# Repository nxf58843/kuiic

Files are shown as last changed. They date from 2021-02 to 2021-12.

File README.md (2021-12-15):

# KUIIC

## K32L2B USB to IIC Kit

This board is a tiny USB to Qwiic development board in a bread-board friendly DIP form factor.  In addition to micro USB and Qwiic connectors, it also has a reset button, RGB LED, and footprint for SPI flash expansion on the back of the board.  The pinout and form factor are designed to be compatible with the Seeeduino XIAO board.  The MCU is an NXP K32L2B Arm Cortex-M0+ with crystal-less USB and integrated VBUS to 3V regulator.  

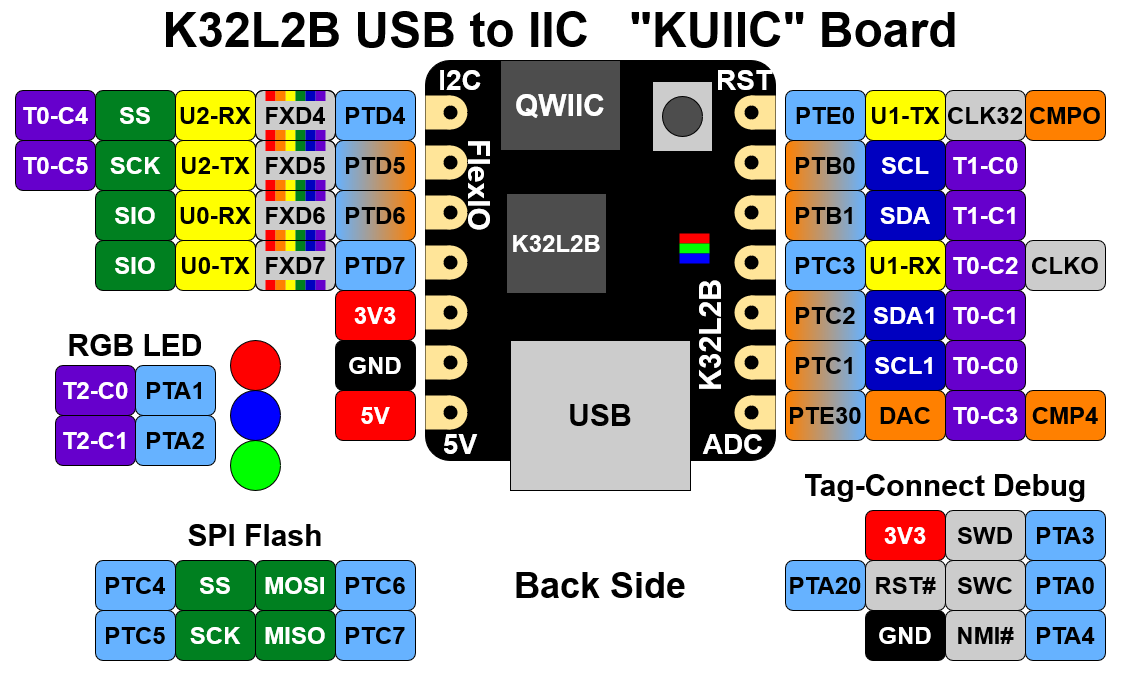
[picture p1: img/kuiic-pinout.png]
Kuiic Pinout


## Software Support

This board is currently supported by the open source [TinyUSB](https://docs.tinyusb.org/en/latest/) and Adafruit's [TinyUF2](https://github.com/adafruit/tinyuf2) to enable drag-n-drop firmware updates.

## Board Design Files
The KiCad source files are included in this repository along with a [pdf copy of the schematic](out/kuiic.pdf).

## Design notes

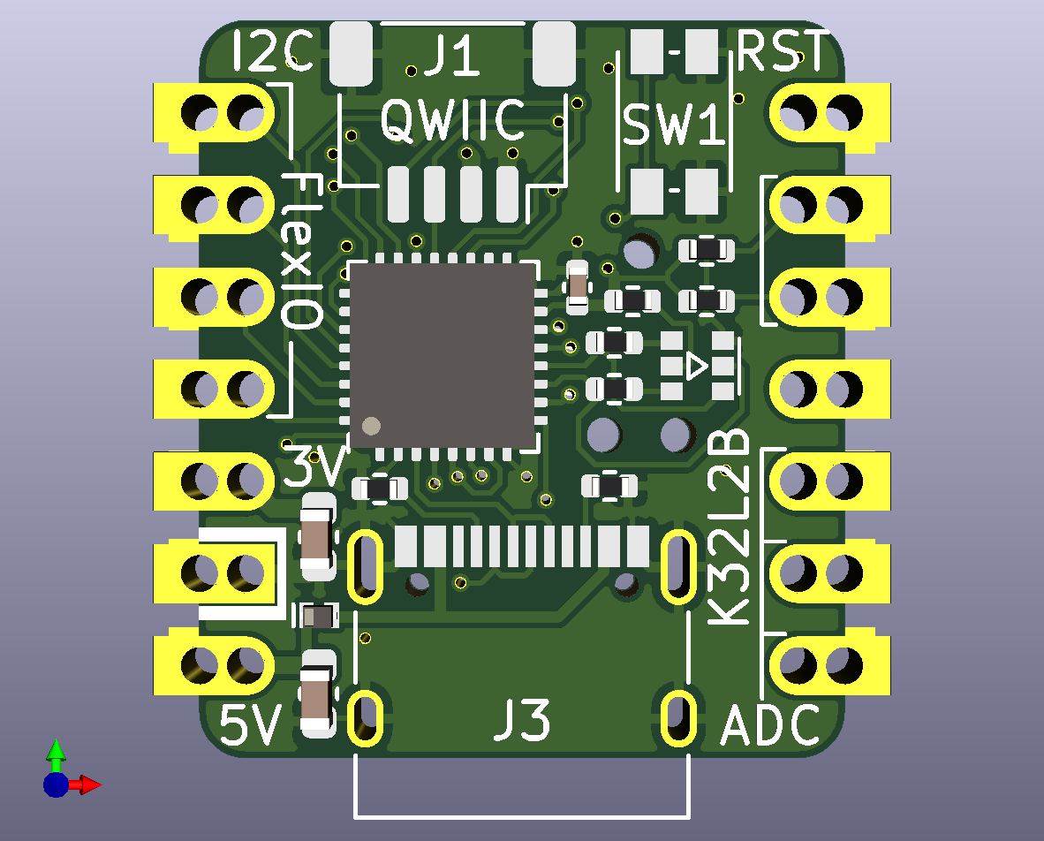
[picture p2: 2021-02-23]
img/k3d-top.png

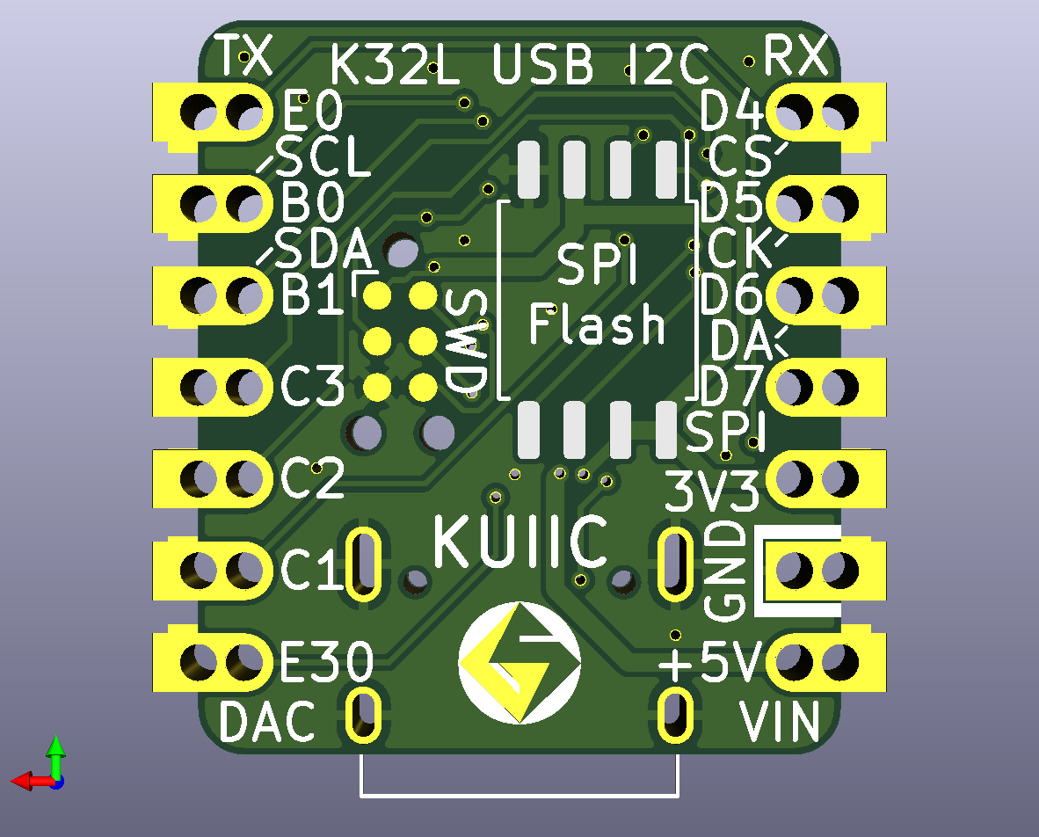
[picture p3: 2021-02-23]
img/k3d-bot.png

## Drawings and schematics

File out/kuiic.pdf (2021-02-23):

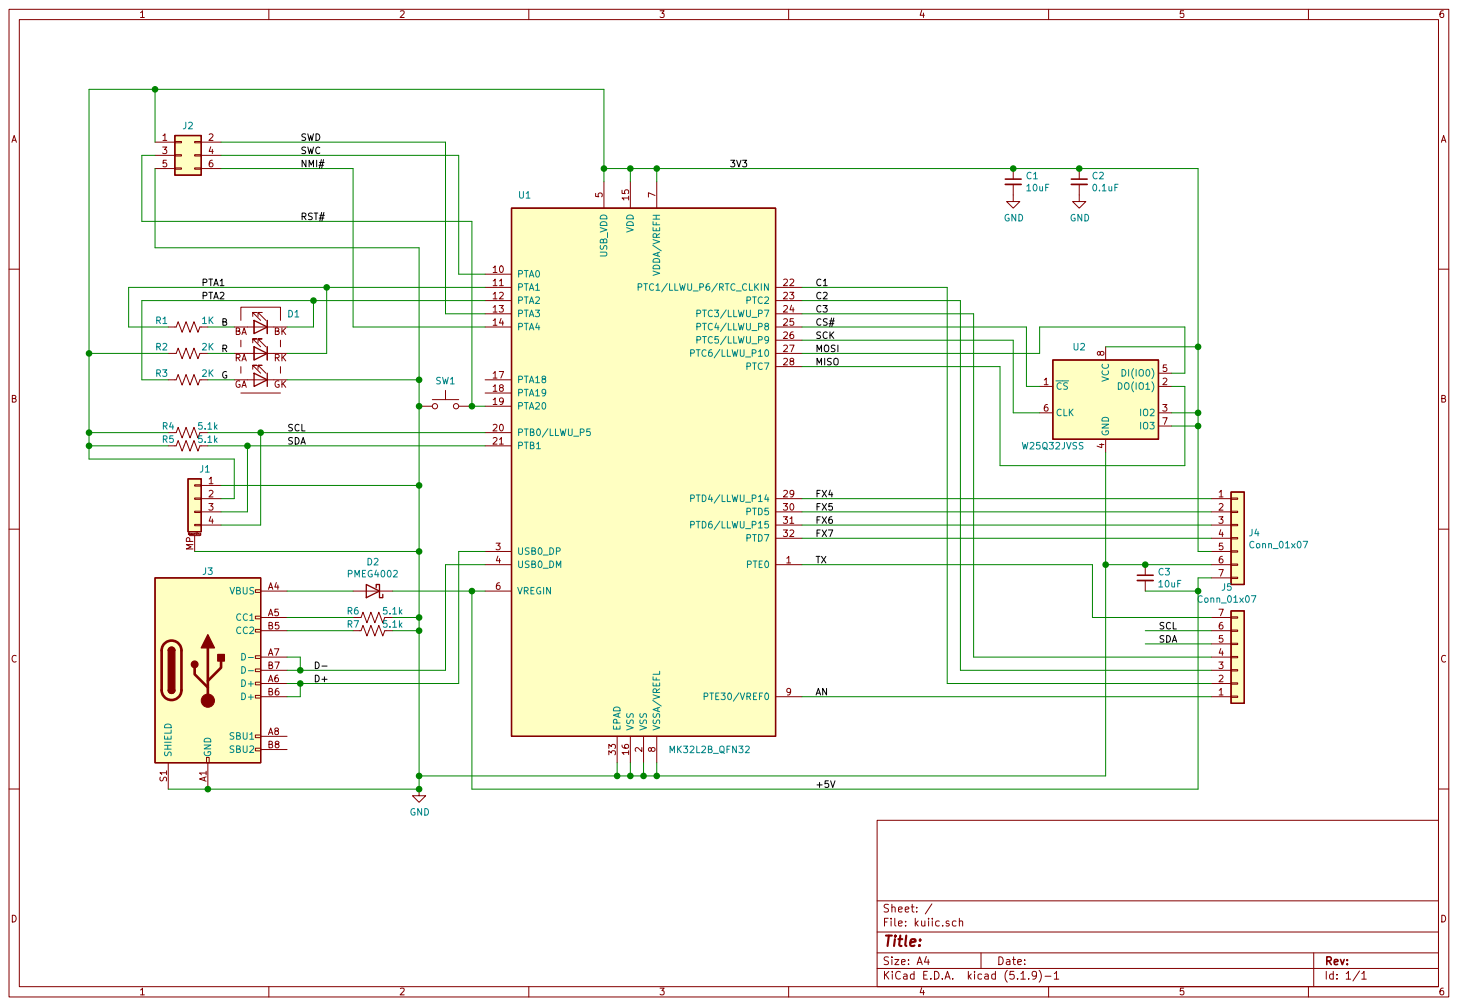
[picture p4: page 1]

TXC1 CS# FX7 SCK MOSI MISO

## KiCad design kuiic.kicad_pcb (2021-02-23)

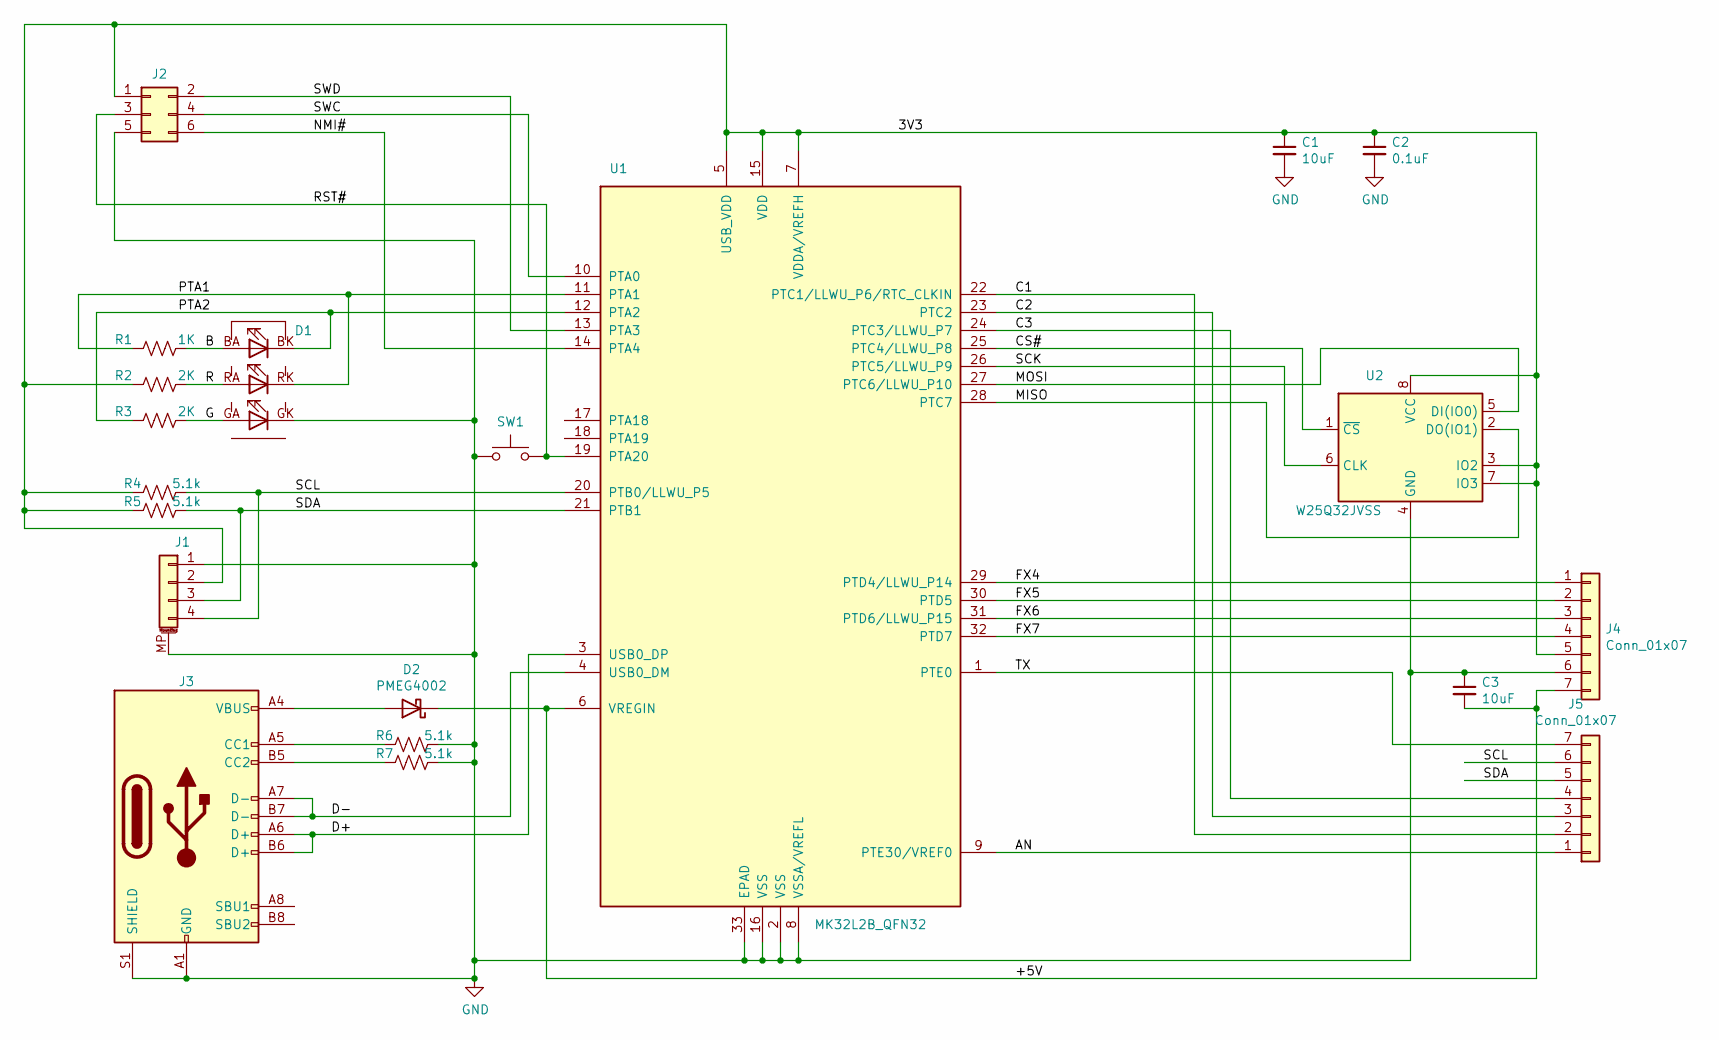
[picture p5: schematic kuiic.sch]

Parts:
C1, C3: 10uF; C_0603_1608Metric; MPN CL10A106KP8NNNC
C2: 0.1uF; C_0402_1005Metric; MPN CC0402KRX7R7BB104
D1: LED_RGB; LED_E6C1615; MPN E6C1615RGBC3UDA
D2: PMEG4002; D_SOD-882; MPN pmeg3005el
J1: Conn_01x04_MountingPin; QWIIC; MPN SM04B-SRSS-TB
J2: Conn_02x03_Odd_Even; Tag-Connect_TC2030-IDC-NL_2x03_P1.27mm_Vertical; MPN DNP
J3: USB_C_Receptacle_USB2.0; USB_C_Receptacle_XKB_U262-16XN-4BVC11; MPN U262-161N-4BVC11
J4, J5: Conn_01x07; PinHeader_1x07_P2.54mm_castle; MPN DNP
R1: 1K; R_0402_1005Metric; MPN RC0402JR-071KL
R2, R3: 2K; R_0402_1005Metric; MPN RC0402JR-072KL
R4, R5, R6, R7: 5.1k; R_0402_1005Metric; MPN RC0402JR-075K1L
SW1: SW_Push; SW_Push_4pin_3.0x3.65mm; MPN TS342A4P-WZ
U1: MK32L2B_QFN32; QFN-32-1EP_5x5mm_P0.5mm_EP3.45x3.45mm; MPN K32L2B31VFM0A
U2: W25Q32JVSS; SOIC-8_5.23x5.23mm_P1.27mm; MPN DNP

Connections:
/3V3: C1.1, C2.1, J1.2, J2.1, J4.5, R2.2, R4.2, R5.2, U1.5 (USB_VDD), U1.7 (VDDA/VREFH), U1.15 (VDD), U2.3 (IO2), U2.7 (IO3), U2.8 (VCC)
/+5V: C3.2, D2.1 (K), J4.7, U1.6 (VREGIN)
/AN: J5.1, U1.9 (PTE30/VREF0)
/B: D1.BA, R1.1
/C1: J5.2, U1.22 (PTC1/LLWU_P6/RTC_CLKIN)
/C2: J5.3, U1.23 (PTC2)
/C3: J5.4, U1.24 (PTC3/LLWU_P7)
/CS#: U1.25 (PTC4/LLWU_P8), U2.1 (~CS)
/D+: J3.A6 (D+), J3.B6 (D+), U1.3 (USB0_DP)
/D-: J3.A7 (D-), J3.B7 (D-), U1.4 (USB0_DM)
/FX4: J4.1, U1.29 (PTD4/LLWU_P14)
/FX5: J4.2, U1.30 (PTD5)
/FX6: J4.3, U1.31 (PTD6/LLWU_P15)
/FX7: J4.4, U1.32 (PTD7)
/G: D1.GA, R3.1
/MISO: U1.28 (PTC7), U2.2 (DO(IO1))
/MOSI: U1.27 (PTC6/LLWU_P10), U2.5 (DI(IO0))
/NMI#: J2.6, U1.14 (PTA4)
/PTA1: D1.RK, R1.2, U1.11 (PTA1)
/PTA2: D1.BK, R3.2, U1.12 (PTA2)
/R: D1.RA, R2.1
/RST#: J2.3, SW1.2, U1.19 (PTA20)
/SCK: U1.26 (PTC5/LLWU_P9), U2.6 (CLK)
/SCL: J1.4, J5.6, R4.1, U1.20 (PTB0/LLWU_P5)
/SDA: J1.3, J5.5, R5.1, U1.21 (PTB1)
/SWC: J2.4, U1.10 (PTA0)
/SWD: J2.2, U1.13 (PTA3)
/TX: J5.7, U1.1 (PTE0)
GND: C1.2, C2.2, C3.1, D1.GK, J1.1, J1.MP (MountPin), J2.5, J3.A1 (GND), J3.A12 (GND), J3.B1 (GND), J3.B12 (GND), J3.S1 (SHIELD), J4.6, R6.1, R7.1, SW1.1, U1.2 (VSS), U1.8 (VSSA/VREFL), U1.16 (VSS), U1.33 (EPAD), U2.4 (GND)
unnamed: D2.2 (A), J3.A4 (VBUS), J3.A9 (VBUS), J3.B4 (VBUS), J3.B9 (VBUS)
unnamed: J3.A5 (CC1), R6.2
unnamed: J3.B5 (CC2), R7.2

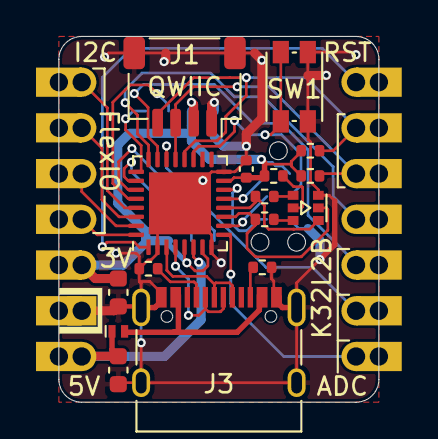
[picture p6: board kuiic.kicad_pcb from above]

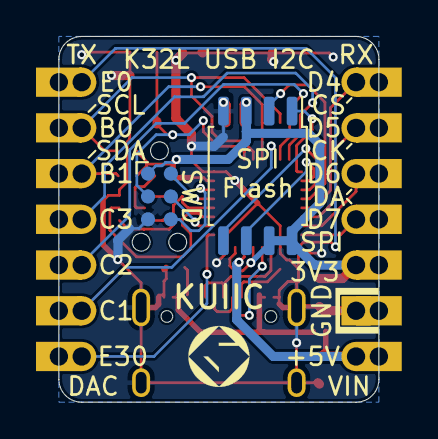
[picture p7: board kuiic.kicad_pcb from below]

Board: 2 copper layers, 17.8 x 20.3 mm, 20 parts (2 on the bottom side), 32 nets.

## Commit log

2021-02-23 initial commit with compplete design
    [kuiic-B_Cu.gbr, kuiic-B_Mask.gbr, kuiic-B_Paste.gbr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]
2021-02-26 flexio pin colors
2021-03-01 extended pads to edge of board
2021-05-10 Condensed ADC inputs and MOSI/MSIO
2021-12-15 added link to schematic to readme
